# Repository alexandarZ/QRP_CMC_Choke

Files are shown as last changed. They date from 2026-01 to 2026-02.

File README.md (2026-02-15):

# QRP CMC Choke (PCB)

A PCB for a lightweight QRP common-mode choke — rated for **up to 10 W (SSB & CW)** or **5 W on FT8**.

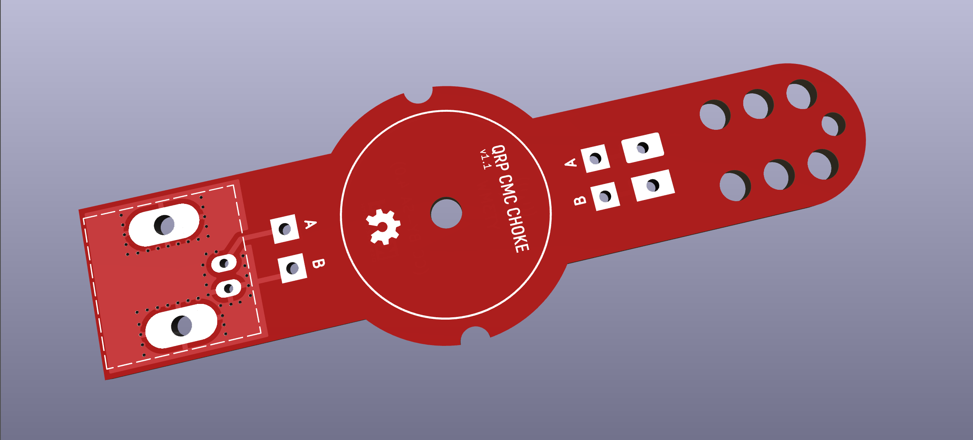
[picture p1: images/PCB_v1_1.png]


---

### Overview
This common-mode choke (CMC) is built around an **Amidon FT82-43** core with a smaller **FT50-43** core nested inside it. The nested arrangement yields a compact, low-loss choke with improved high-frequency behaviour compared with a single core of the same outer size — an excellent choice for QRP use where minimal dissipation and a small form factor matter.

---

### Recommended cores
- **Outer core:** Amidon FT82-43 (or Fair-Rite equivalent 5943000601)  
- **Inner core:** Amidon / Fair-Rite FT50-43 (5943001101) placed inside the FT82-43  
- **Alternative (high bands only):** Würth 74270118 — performs well on higher frequencies but **not recommended below ~6 MHz**.

---

### Practical guidance
- For 40–10 m common-mode suppression, start with **~8–10 symmetrical turns** of 0.4mm2 enamelled wire, which are usually sufficient for typical QRP antenna setups.
- More turns increase common-mode impedance at lower frequencies, but also raise inter-winding capacitance — measure and adjust for your target bands.  
- Aim for **at least 20 dB of common-mode attenuation** across the target band where practical.  
- Target an **SWR as close to 1:1 as possible** after installing the choke; SWR below **1.5:1** is generally acceptable for most QRP uses.

**Wire & mechanical tips**
- Use enamelled copper wire sized appropriately for your power and mechanical needs — commonly 0.4–0.6 mm enamelled wire works well for QRP.  
- Keep pigtails and external leads short to avoid added series inductance.  
- Secure the nested cores mechanically with non-conductive tape or heat-shrink to prevent rotation or movement.

---

### How to test the CMC choke
Recommended guide (detailed):  
- Measuring common-mode choke performance — Lance Conry.  
  https://lance.conryclan.com/home/measuring-common-mode-choke-performance/

Quick checklist:
1. **Calibrate** your VNA for the measurement band.  
2. **Measure S21 parameter** in common-mode configuration to estimate CMC attenuation.
3. **Measure S21 parameter** in insertion loss configuration to estimate CMC insertion loss  
4. **Measure impedance / Z** vs frequency to verify target common-mode impedance.  
5. **Verify SWR** of your antenna/system with the choke installed to confirm no adverse effects.  

---

### Build results

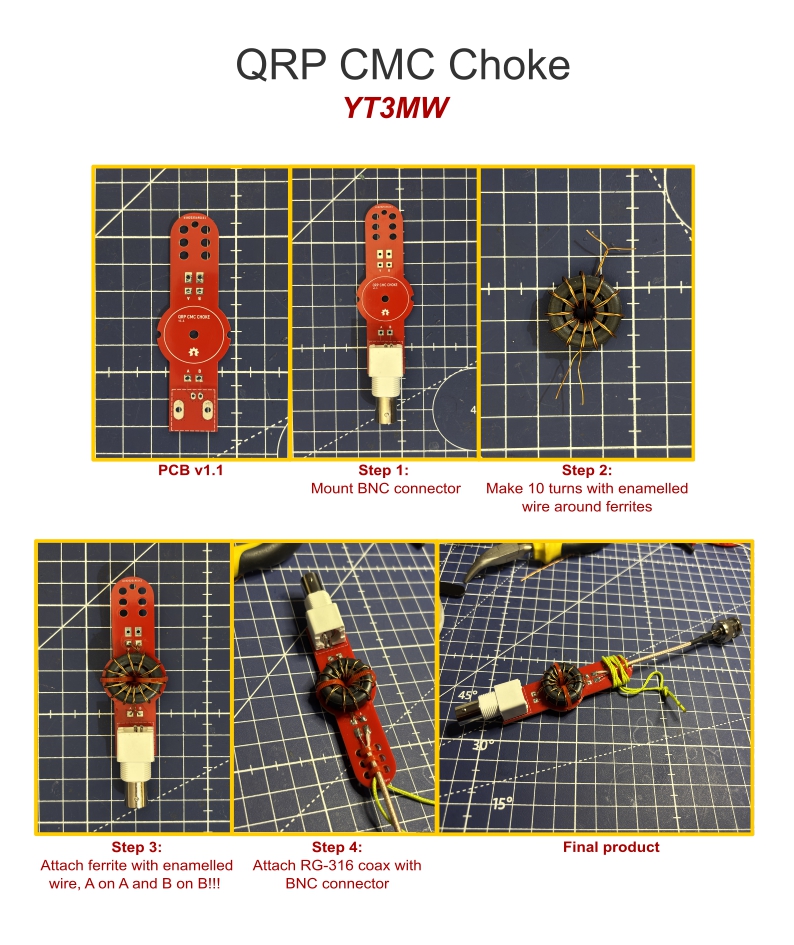
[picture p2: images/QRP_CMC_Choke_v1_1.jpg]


| Band | CMC attenuation (dB) | Insertion loss (dB) | VSWR |
|---|---:|---:|---:|
| 80 m  | -29.63 dB | -0.09 dB | 1.008 |
| 40 m  | -32.78 dB | -0.21 dB | 1.014 |
| 30 m  | -33.96 dB | -0.29 dB | 1.019 |
| 20 m  | -34.39 dB | -0.32 dB | 1.026 |
| 17 m  | -34.16 dB | -0.34 dB | 1.037 |
| 15 m  | -33.45 dB | -0.33 dB | 1.047 |
| 12 m  | -32.24 dB | -0.34 dB | 1.059 |
| 10 m  | -30.62 dB | -0.35 dB | 1.073 |

## Build / Manufacture

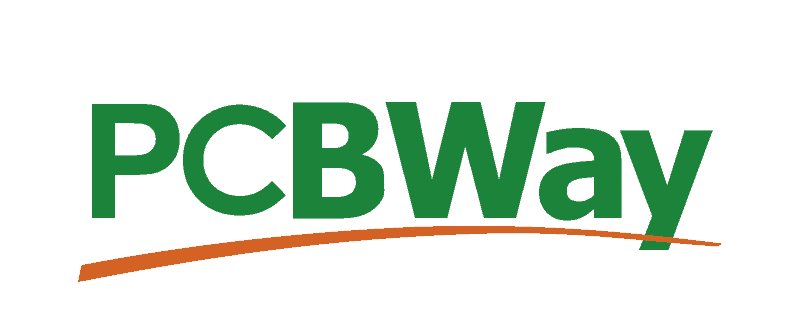
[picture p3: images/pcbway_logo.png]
PCBWay logo


I had a PCB manufactured for my project by **PCBWay** company and the experience was outstanding. The ordering process was straightforward, Gerber review options clear, and the price — considering the final product — is very economical. The build cost is low, yet the result feels far from cheap.
Quality of manufacture is top-tier: fine trace definition, neat vias, and excellent tolerance control. The board looks phenomenal — professional finish, crisp silkscreen, and clean markings. After assembly the choke behaved exactly as expected; the performance and results are of very high quality.
I recommend this company to anyone producing similar boards — great value for money and reliable results. Big thanks to the team for the fast, precise work and for helping bring this project to life.

**Gerber files:**  
FT82 version: `./gerbers/FT82_43_CMC_Choke.zip`  

### Recommended settings
Use the following manufacturing parameters when placing the order:

- **Board thickness:** `1.6 mm`  
- **Layers:** `2 (two-layer)`  
- **Material:** `FR-4`  
- **Copper weight:** `1 oz (35 µm)`  
- **Solder mask:** Chose your preferred

### 73s de YT3MW

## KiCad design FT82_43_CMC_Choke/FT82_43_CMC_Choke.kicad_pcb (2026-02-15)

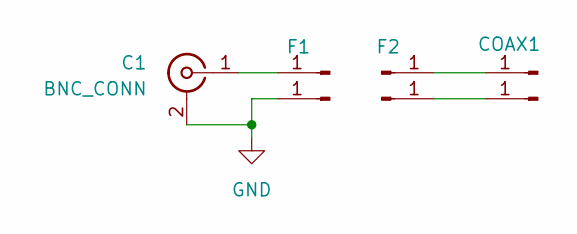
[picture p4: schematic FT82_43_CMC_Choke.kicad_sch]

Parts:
C1: BNC_CONN; BNC_Amphenol_B6252HB-NPP3G-50_Horizontal
COAX1: Conn_01x01_Pin; TestPoint_THTPad_2.5x2.5mm_Drill1.2mm
F1, F2: Conn_01x01_Pin; TestPoint_THTPad_2.5x2.5mm_Drill1.2mm
J1, J4, J6: Conn_01x01_Pin; TestPoint_THTPad_2.5x2.5mm_Drill1.2mm

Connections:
GND: C1.2 (Ext), F1.1
unnamed: C1.1 (In), J1.1
unnamed: COAX1.1, J4.1
unnamed: F2.1, J6.1

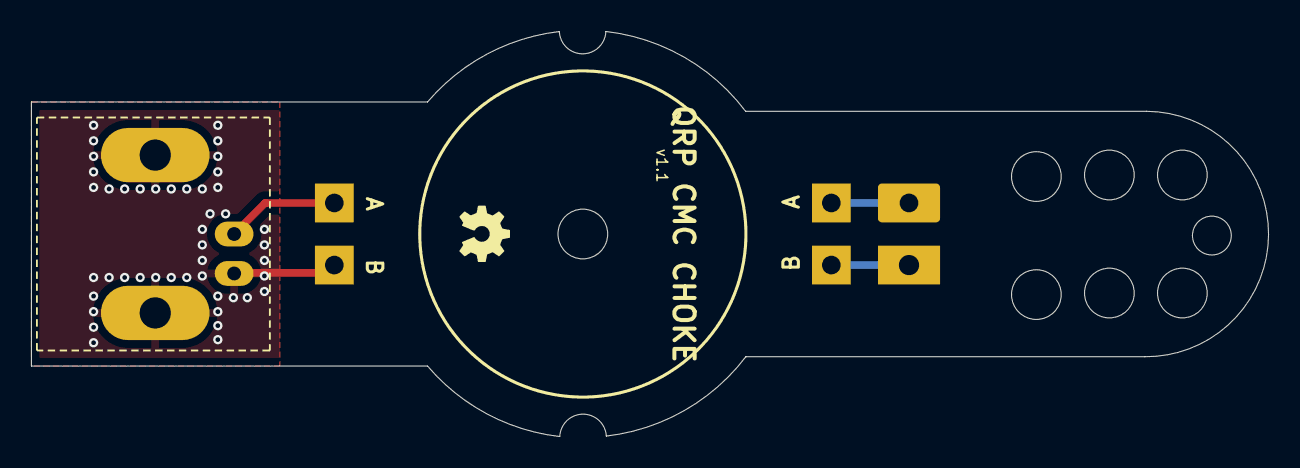
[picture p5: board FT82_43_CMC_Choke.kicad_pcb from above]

Board: 2 copper layers, 79.6 x 26.1 mm, 7 parts (0 on the bottom side), 4 nets.

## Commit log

2026-01-01 PCB v1.1 and updates
    [FT82_43_CMC_Choke.kicad_pcb, FT82_43_CMC_Choke.kicad_sch]
2026-01-12 Gerber for PCB v1.1
    [FT114_43_CMC_Choke.kicad_pcb, FT114_43_CMC_Choke.kicad_sch, FT82_43_CMC_Choke.kicad_pcb]
2026-02-15 PCB v1_1 :)
    [FT114_43_CMC_Choke.kicad_pcb, FT114_43_CMC_Choke.kicad_sch, FT82_43_CMC_Choke.kicad_pcb]

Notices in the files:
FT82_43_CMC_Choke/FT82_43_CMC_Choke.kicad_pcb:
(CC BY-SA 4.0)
